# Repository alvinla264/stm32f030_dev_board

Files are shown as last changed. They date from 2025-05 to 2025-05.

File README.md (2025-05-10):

# STM32F030 Dev Board

This is a custom development board for the STM32F030RCT6 with USB-C and FT232H for USB-to-serial communication and SWD ports for debugging. Designed as a 4-layer board.

---

## 📷 Schematic

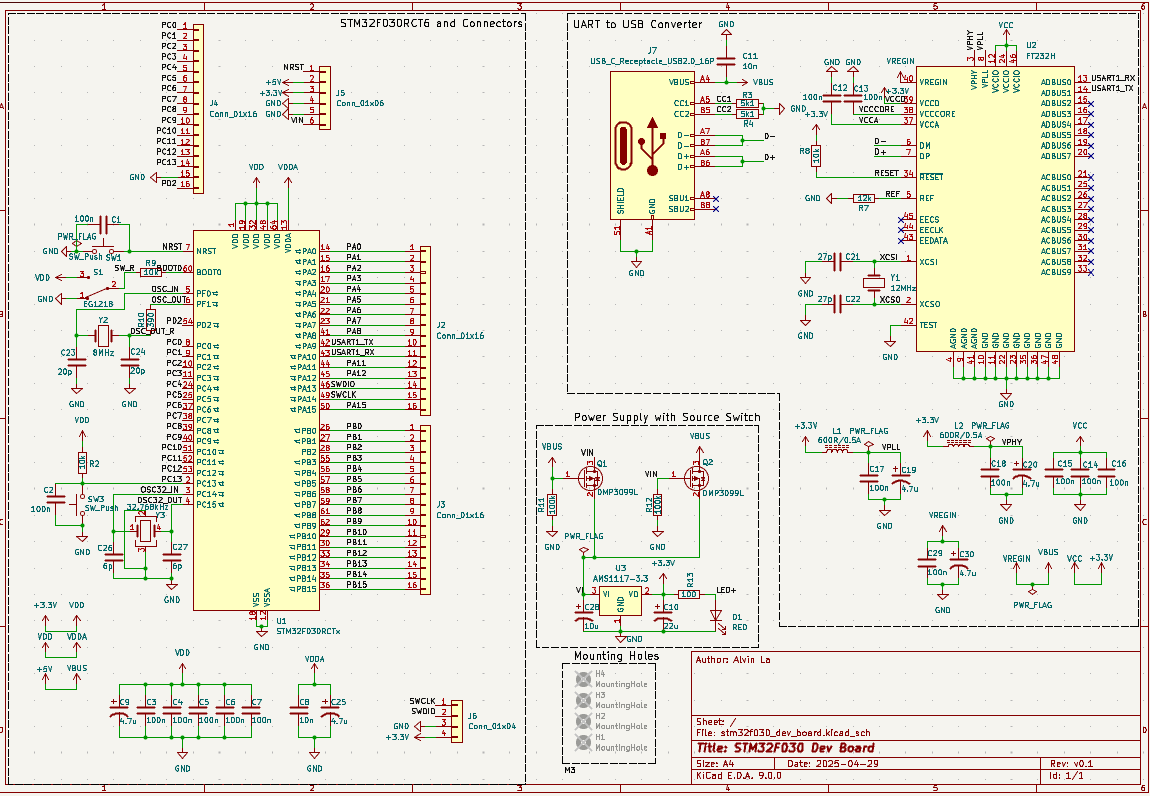
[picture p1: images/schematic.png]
Schematic


---

## 🖼️ PCB Layout

### 2D Layout:
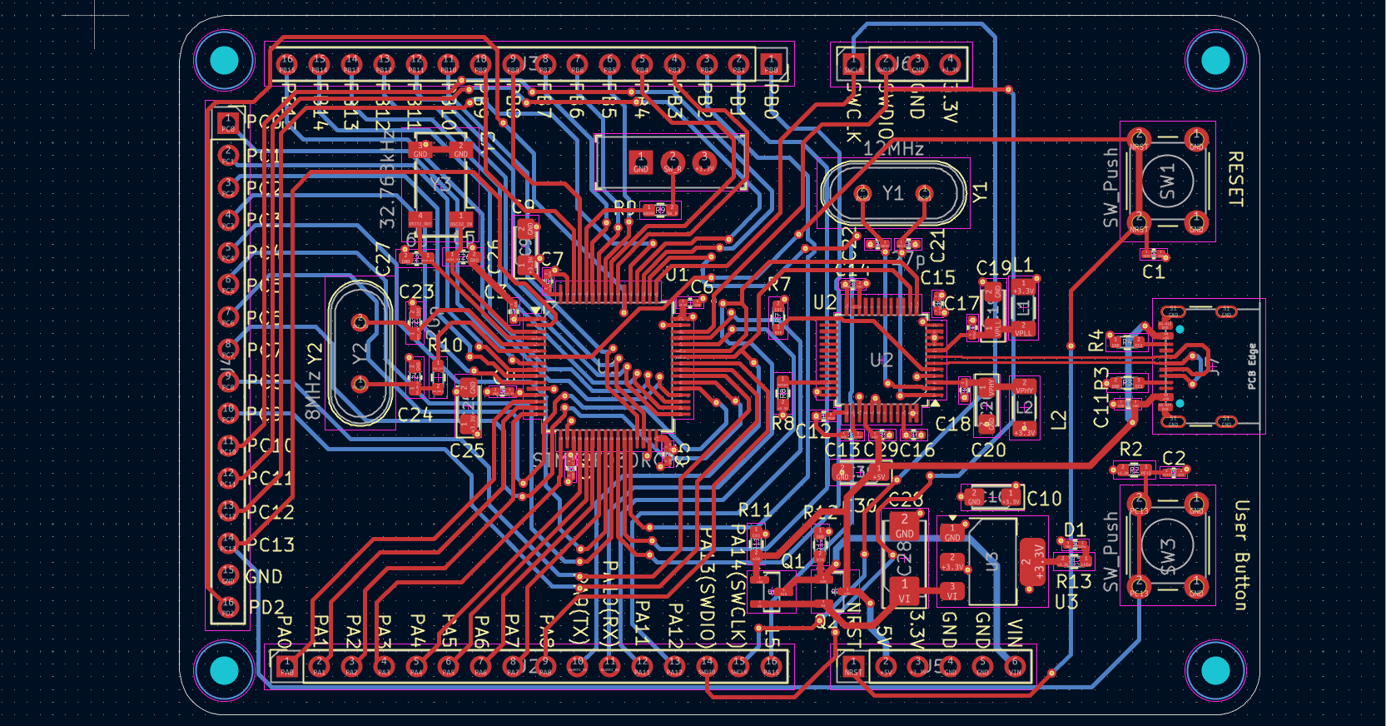
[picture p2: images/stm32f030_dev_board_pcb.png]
PCB Layout


### 3D Preview:
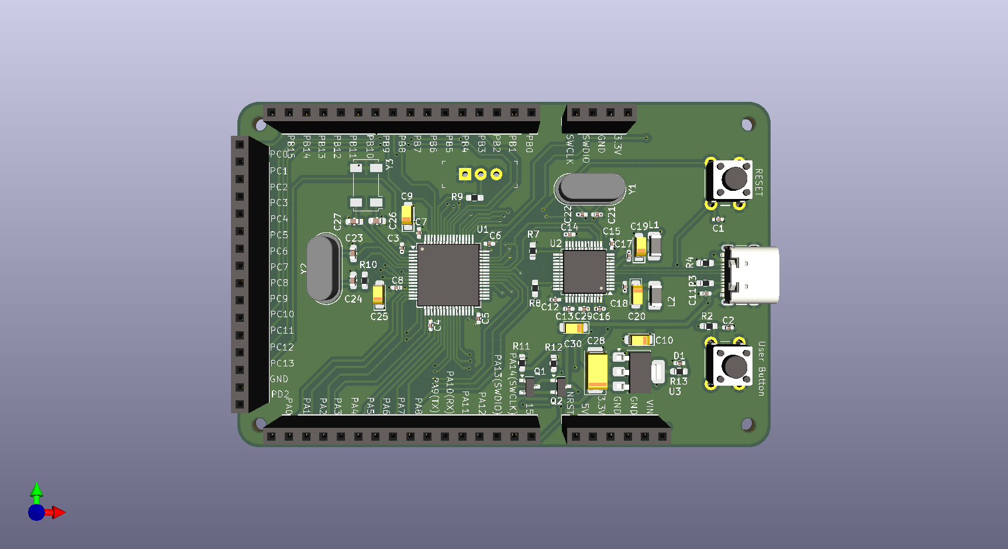
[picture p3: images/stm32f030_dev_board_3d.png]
3D View


---

## 🔧 Stackup

- Layer 1 (Top): Signal + GND pours
- Layer 2: GND
- Layer 3: Power (3.3V plane)
- Layer 4 (Bottom): Signal + GND pours

---

## 📌 Features

- STM32F030RCT6 (64-pin LQFP)
- USB-C for power and data
- FT232H for USB-to-UART
- SWD ports for debugging
- Decoupling and filtering capacitors throughout

---

## 💡 Status

- ✔️ Schematic complete
- ✔️ PCB layout complete
- ❌ Via Stitching in progress
- ❌ Testing and fabrication in progress

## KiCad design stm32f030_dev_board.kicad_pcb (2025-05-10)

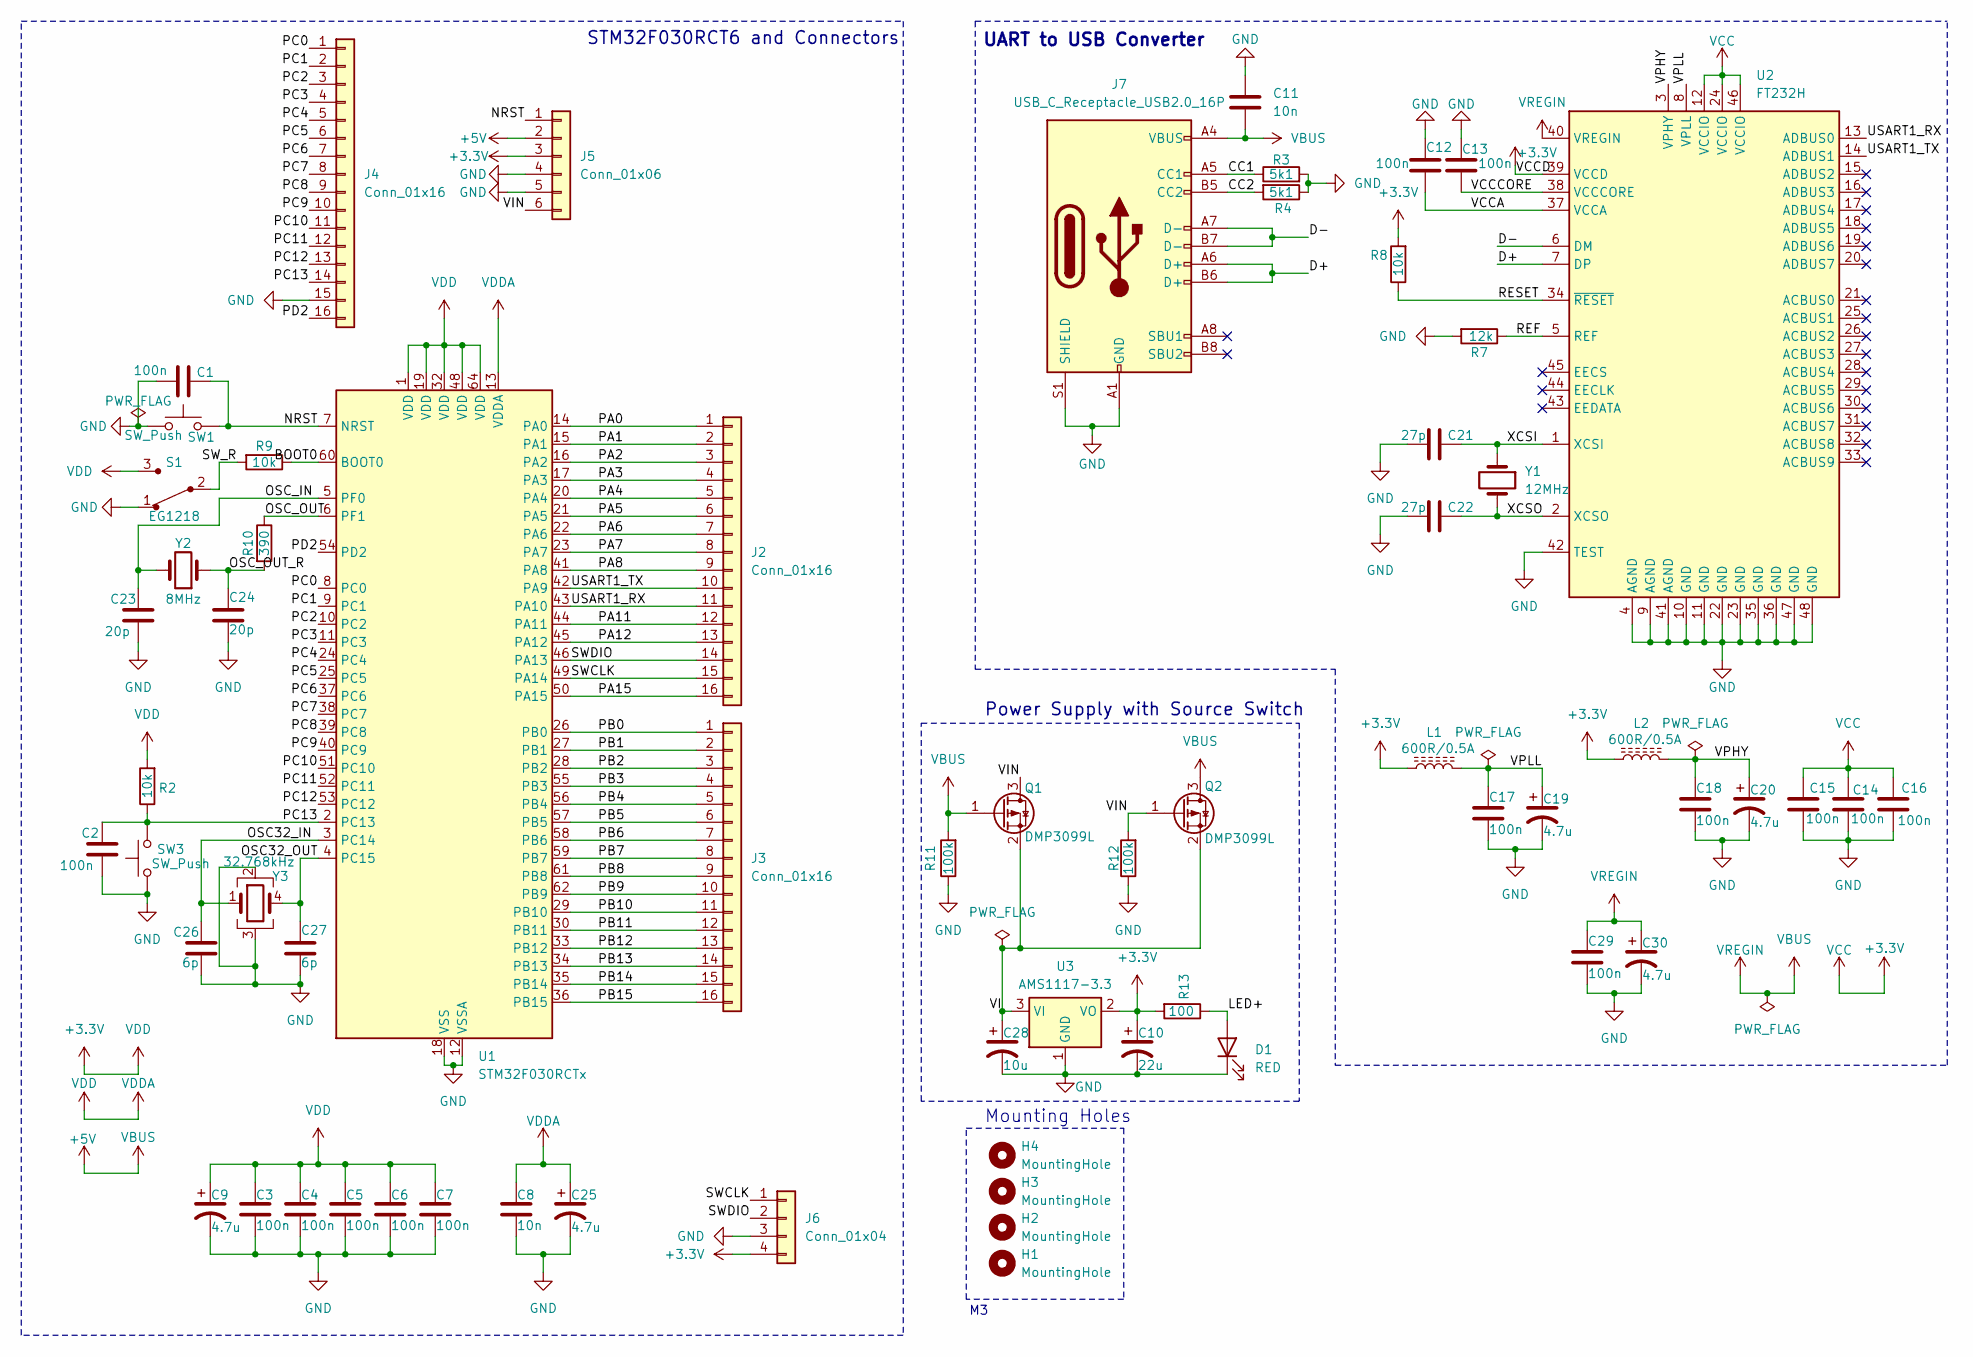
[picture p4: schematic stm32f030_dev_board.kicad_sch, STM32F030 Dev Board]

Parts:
C1, C2, C3, C4, C5, C6, C7, C12, C13, C14, C15, C16, C17, C18, C29: 100n; C_0402_1005Metric_Pad0.74x0.62mm_HandSolder
C8, C11: 10n; C_0402_1005Metric_Pad0.74x0.62mm_HandSolder
C9, C19, C20, C25, C30: 4.7u; CP_EIA-3216-18_Kemet-A_Pad1.58x1.35mm_HandSolder
C10: 22u; CP_EIA-3216-18_Kemet-A_Pad1.58x1.35mm_HandSolder
C21, C22: 27p; C_0402_1005Metric_Pad0.74x0.62mm_HandSolder
C23, C24: 20p; C_0603_1608Metric_Pad1.08x0.95mm_HandSolder
C26, C27: 6p; C_0603_1608Metric_Pad1.08x0.95mm_HandSolder
C28: 10u; CP_EIA-6032-28_Kemet-C_Pad2.25x2.35mm_HandSolder
D1: RED; C_0402_1005Metric_Pad0.74x0.62mm_HandSolder
H1, H2, H3, H4: MountingHole; MountingHole_2.2mm_M2
J2, J3, J4: Conn_01x16; PinSocket_1x16_P2.54mm_Vertical
J5: Conn_01x06; PinSocket_1x06_P2.54mm_Vertical
J6: Conn_01x04; PinSocket_1x04_P2.54mm_Vertical
J7: USB_C_Receptacle_USB2.0_16P; USB_C_Receptacle_GCT_USB4105-xx-A_16P_TopMnt_Horizontal
L1, L2: 600R/0.5A; L_1206_3216Metric_Pad1.22x1.90mm_HandSolder
Q1, Q2: DMP3099L; SOT-23
R2, R8, R9: 10k; R_0603_1608Metric_Pad0.98x0.95mm_HandSolder
R3, R4: 5k1; R_0603_1608Metric_Pad0.98x0.95mm_HandSolder
R7: 12k; R_0603_1608Metric_Pad0.98x0.95mm_HandSolder
R10: 390; R_0603_1608Metric_Pad0.98x0.95mm_HandSolder
R11, R12: 100k; R_0603_1608Metric_Pad0.98x0.95mm_HandSolder
R13: 100; R_0603_1608Metric_Pad0.98x0.95mm_HandSolder
S1: EG1218; Switch_Slide_11.6x4mm_EG1218; MPN EG1218; Digi-Key_PN EG1903-ND
SW1, SW3: SW_Push; SW_PUSH_6mm_H5mm
U1: STM32F030RCTx; LQFP-64_10x10mm_P0.5mm
U2: FT232H; LQFP-48_7x7mm_P0.5mm
U3: AMS1117-3.3; SOT-223-3_TabPin2
Y1: 12MHz; Crystal_HC49-4H_Vertical
Y2: 8MHz; Crystal_HC49-4H_Vertical
Y3: 32.768kHz; Crystal_SMD_Abracon_ABS25-4Pin_8.0x3.8mm

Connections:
+3.3V: C3.1, C4.1, C5.1, C6.1, C7.1, C8.1, C9.1, C10.1, C14.1, C15.1, C16.1, C25.1, J5.3, J6.4, L1.1, L2.1, R2.2, R8.2, R13.2, S1.3, U1.1 (VDD), U1.13 (VDDA), U1.19 (VDD), U1.32 (VDD), U1.48 (VDD), U1.64 (VDD), U2.12 (VCCIO), U2.24 (VCCIO), U2.39 (VCCD), U2.46 (VCCIO), U3.2 (VO)
+5V: C11.2, C29.1, C30.1, J5.2, J7.A4 (VBUS), J7.A9 (VBUS), J7.B4 (VBUS), J7.B9 (VBUS), Q1.1 (G), Q2.3 (D), R11.2, U2.40 (VREGIN)
/BOOT0: R9.1, U1.60 (BOOT0)
/CC1: J7.A5 (CC1), R3.1
/CC2: J7.B5 (CC2), R4.2
/D+: J7.A6 (D+), J7.B6 (D+), U2.7 (DP)
/D-: J7.A7 (D-), J7.B7 (D-), U2.6 (DM)
/LED+: D1.2 (A), R13.1
/NRST: C1.1, J5.1, SW1.2, U1.7 (NRST)
/OSC32_IN: C26.1, U1.3 (PC14), Y3.1
/OSC32_OUT: C27.1, U1.4 (PC15), Y3.4
/OSC_IN: C23.1, U1.5 (PF0), Y2.2
/OSC_OUT: R10.1, U1.6 (PF1)
/OSC_OUT_R: C24.1, R10.2, Y2.1
/PA0: J2.1, U1.14 (PA0)
/PA1: J2.2, U1.15 (PA1)
/PA2: J2.3, U1.16 (PA2)
/PA3: J2.4, U1.17 (PA3)
/PA4: J2.5, U1.20 (PA4)
/PA5: J2.6, U1.21 (PA5)
/PA6: J2.7, U1.22 (PA6)
/PA7: J2.8, U1.23 (PA7)
/PA8: J2.9, U1.41 (PA8)
/PA11: J2.12, U1.44 (PA11)
/PA12: J2.13, U1.45 (PA12)
/PA15: J2.16, U1.50 (PA15)
/PB0: J3.1, U1.26 (PB0)
/PB1: J3.2, U1.27 (PB1)
/PB2: J3.3, U1.28 (PB2)
/PB3: J3.4, U1.55 (PB3)
/PB4: J3.5, U1.56 (PB4)
/PB5: J3.6, U1.57 (PB5)
/PB6: J3.7, U1.58 (PB6)
/PB7: J3.8, U1.59 (PB7)
/PB8: J3.9, U1.61 (PB8)
/PB9: J3.10, U1.62 (PB9)
/PB10: J3.11, U1.29 (PB10)
/PB11: J3.12, U1.30 (PB11)
/PB12: J3.13, U1.33 (PB12)
/PB13: J3.14, U1.34 (PB13)
/PB14: J3.15, U1.35 (PB14)
/PB15: J3.16, U1.36 (PB15)
/PC0: J4.1, U1.8 (PC0)
/PC1: J4.2, U1.9 (PC1)
/PC2: J4.3, U1.10 (PC2)
/PC3: J4.4, U1.11 (PC3)
/PC4: J4.5, U1.24 (PC4)
/PC5: J4.6, U1.25 (PC5)
/PC6: J4.7, U1.37 (PC6)
/PC7: J4.8, U1.38 (PC7)
/PC8: J4.9, U1.39 (PC8)
/PC9: J4.10, U1.40 (PC9)
/PC10: J4.11, U1.51 (PC10)
/PC11: J4.12, U1.52 (PC11)
/PC12: J4.13, U1.53 (PC12)
/PC13: C2.1, J4.14, R2.1, SW3.2, U1.2 (PC13)
/PD2: J4.16, U1.54 (PD2)
/REF: R7.1, U2.5 (REF)
/RESET: R8.1, U2.34 (~RESET)
/SWCLK: J2.15, J6.1, U1.49 (PA14)
/SWDIO: J2.14, J6.2, U1.46 (PA13)
/SW_R: R9.2, S1.2
/USART1_RX: J2.11, U1.43 (PA10), U2.13 (ADBUS0)
/USART1_TX: J2.10, U1.42 (PA9), U2.14 (ADBUS1)
/VCCA: C12.2, U2.37 (VCCA)
/VCCCORE: C13.2, U2.38 (VCCCORE)
/VI: C28.1, Q1.2 (S), Q2.2 (S), U3.3 (VI)
/VIN: J5.6, Q1.3 (D), Q2.1 (G), R12.2
/VPHY: C18.1, C20.1, L2.2, U2.3 (VPHY)
/VPLL: C17.1, C19.1, L1.2, U2.8 (VPLL)
/XCSI: C21.1, U2.1 (XCSI), Y1.1
/XCSO: C22.1, U2.2 (XCSO), Y1.2
GND: C1.2, C2.2, C3.2, C4.2, C5.2, C6.2, C7.2, C8.2, C9.2, C10.2, C11.1, C12.1, C13.1, C14.2, C15.2, C16.2, C17.2, C18.2, C19.2, C20.2, C21.2, C22.2, C23.2, C24.2, C25.2, C26.2, C27.2, C28.2, C29.2, C30.2, D1.1 (K), J4.15, J5.4, J5.5, J6.3, J7.A1 (GND), J7.A1-B12 (GND), J7.A12 (GND), J7.B1 (GND), J7.B1-A12 (GND), J7.B12 (GND), J7.S1 (SHIELD), R3.2, R4.1, R7.2, R11.1, R12.1, S1.1, SW1.1, SW3.1, U1.12 (VSSA), U1.18 (VSS), U1.31 (VSS), U1.47 (VSS), U1.63 (VSS), U2.4 (AGND), U2.9 (AGND), U2.10 (GND), U2.11 (GND), U2.22 (GND), U2.23 (GND), U2.35 (GND), U2.36 (GND), U2.41 (AGND), U2.42 (TEST), U2.47 (GND), U2.48 (GND), U3.1 (GND), Y3.2, Y3.3

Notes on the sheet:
Mounting Holes
UART to USB Converter
STM32F030RCT6 and Connectors
Power Supply with Source Switch

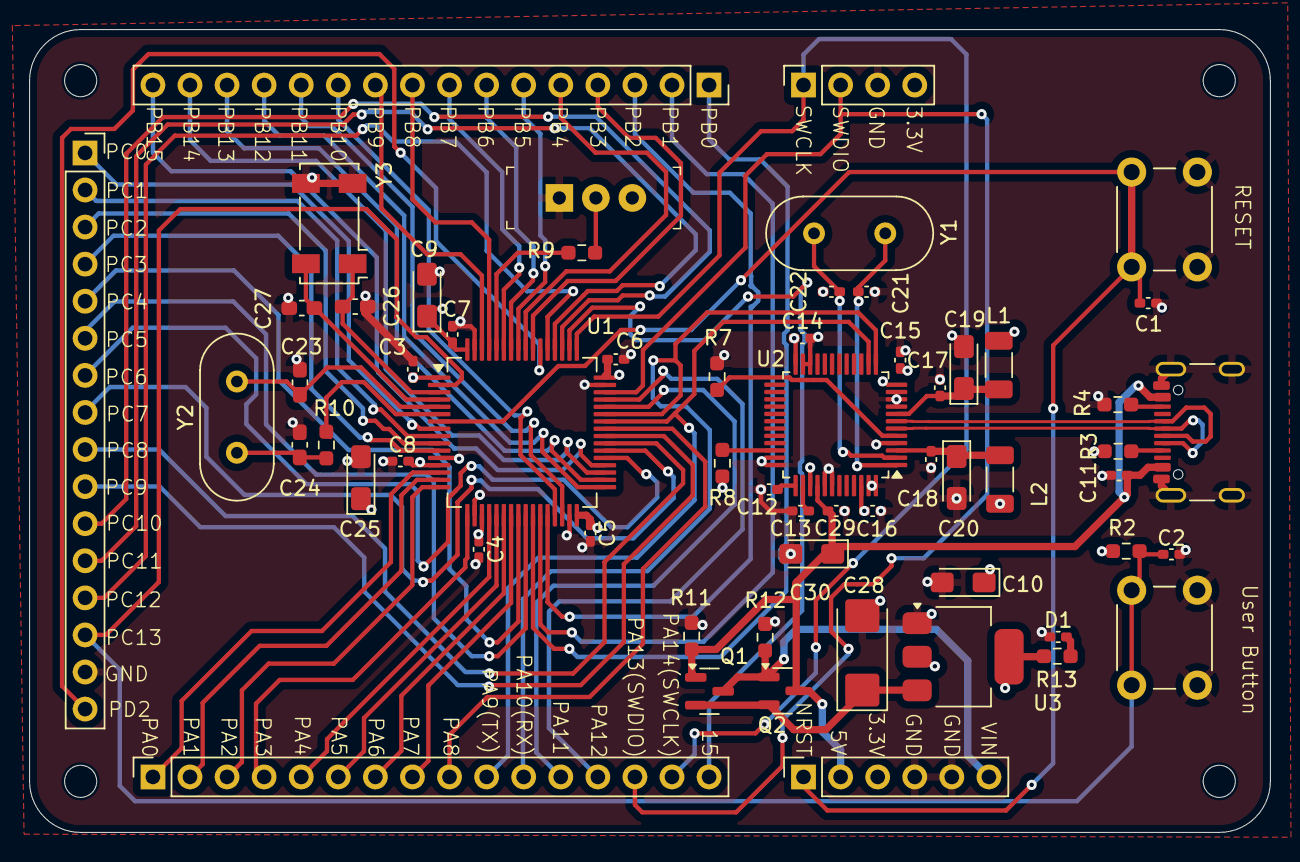
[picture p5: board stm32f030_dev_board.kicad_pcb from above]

Board: 4 copper layers, 85.0 x 55.0 mm, 64 parts (0 on the bottom side), 73 nets.

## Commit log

2025-05-02 Started PCB layout and added net labels to schematic
    [stm32f030_dev_board.kicad_pcb, stm32f030_dev_board.kicad_sch]
2025-05-03 Layout the pcb and added mounting holes to schematic and pcb
    [stm32f030_dev_board.kicad_pcb, stm32f030_dev_board.kicad_sch]
2025-05-03 Fix Edge Cuts to have rounded corners
    [stm32f030_dev_board.kicad_pcb]
2025-05-03 Adjusted Spacing between pin headers
    [stm32f030_dev_board.kicad_pcb]
2025-05-05 removed D+ and D- resistors, finished routing front and back copper, moved button to better place
    [stm32f030_dev_board.kicad_pcb, stm32f030_dev_board.kicad_sch]
2025-05-06 Finished routing, Added silk screen labels for ports, fixed USB C footprint(removed stacked pads for ground pins)
    [stm32f030_dev_board.kicad_pcb]
2025-05-07 fixed silkscreen overlap and updated .gitignore
    [stm32f030_dev_board.kicad_pcb]
2025-05-10 Switched to 4 layer board stackup and rerouted
    [stm32f030_dev_board.kicad_pcb]
2025-05-10 Fixed 2d pcb image and readme
